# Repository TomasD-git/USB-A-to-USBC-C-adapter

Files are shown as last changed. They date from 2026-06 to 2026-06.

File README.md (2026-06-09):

# USB-A-to-USBC-C-adapter
**Compact USB-A to USB-C adapter, supports USB 3.1 speeds, with stable power**

<details>
<summary>Features</summary>
  
-Small  
-Very fast  
-1 Layer PCBA  
  
</details>

<details>
  <summary>BOM</summary>

# BOM
 
| Name | Purpose | Quantity | Total Cost (USD) | Link | Distributor |
|---|---|---|---|---|---|
| PCB | all components are on this | 1 | 15 | [jlcpcb](https://jlcpcb.com) | jlcpcb |
| ALL components | all components that are on pcb | 1 | 25 | [lcsc](https://lcsc.com) | lcsc |
| | | **Total cost** | **40** | | |

</details>







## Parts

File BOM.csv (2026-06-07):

Name | Purpose | Quantity | Total Cost (USD) | Link | Distributor
PCB | all components are on this | 1 | 15 | https://jlcpcb.com | jlcpcb
ALL components | all components that are on pcb | 1 | 25 | https://lcsc.com | lcsc
 |  | Total cost | 40

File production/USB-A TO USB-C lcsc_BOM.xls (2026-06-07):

JLCPCB BOM Tool - BOM Matching
BOM name：bom-JLCPCB Assembly Order.xlsx |  |  | Download Time：2026-06-08 02:33:23 |  |  |  | * Our matching results are updated in real-time, but stock and prices may change. If it's been over 24 hours, please re-match before placing your order.
PCB Assembled Qty：5 |  |  | Est. Total Price：21.4874
Your BOM |  |  |  |  | Matched Parts |  |  |  |  |  |  | Order Information
Top Designator | Bottom Designator | Comment | Footprint | JLCPCB Part # | Matches | Part # | Manufacturer | Footprint | Description | Category | Warning | JLCPCB Part # | Product link | Lib Type | Qty | Source | Total Price ($)
C1,C10,C2,C4,C7 |  | 100nF | 0402 |  | Select by System | CL05B104KO5NNNC | Samsung Electro-Mechanics | 0402 | 100nF 16V X7R ±10% 0402 Multilayer Ceramic Capacitors MLCC - SMD/SMT ROHS | Multilayer Ceramic Capacitors MLCC - SMD/SMT |  | C1525 | https://jlcpcb.com/partdetail/1877-CL05B104KO5NNNC/C1525 | Basic | 35 | 35 JLCPCB | 0.0735
C3,C5,C8 |  | 1uF | 0603 |  | Select by System | CL10A105KB8NNNC | Samsung Electro-Mechanics | 0603 | 1uF 50V X5R ±10% 0603 Multilayer Ceramic Capacitors MLCC - SMD/SMT ROHS | Multilayer Ceramic Capacitors MLCC - SMD/SMT |  | C15849 | https://jlcpcb.com/partdetail/16531-CL10A105KB8NNNC/C15849 | Basic | 25 | 25 JLCPCB | 0.2675
C6,C9 |  | 10uF | 0805 |  | Select by System | GRM21BR61H106KE43L | Murata Electronics | 0805 | 10uF 50V X5R ±10% 0805 Multilayer Ceramic Capacitors MLCC - SMD/SMT ROHS | Multilayer Ceramic Capacitors MLCC - SMD/SMT |  | C440198 | https://jlcpcb.com/partdetail/439567-GRM21BR61H106KE43L/C440198 | Basic | 14 | 14 JLCPCB | 4.3134
R1 |  | 4.7K | 0603 |  | Unconfirmed | 0603WAF4701T5E | UNI-ROYAL(Uniroyal Elec) | 0603 | -55℃~+155℃ 100mW 4.7kΩ 75V Thick Film Resistor ±1% ±100ppm/℃ 0603 Chip Resistor - Surface Mount ROHS | Chip Resistor - Surface Mount | 1.The comment (0603WAF4701T5E) of this part does not match the one (4.7K) provided in your BOM. Please confirm; | C23162 | https://jlcpcb.com/partdetail/23889-0603WAF4701T5E/C23162 | Basic | 20 | 20 JLCPCB | 0.028
R2 |  | 900K | 0603 |  | Select by Customer | 0603WAF4703T5E | UNI-ROYAL(Uniroyal Elec) | 0603 | -55℃~+155℃ 100mW 470kΩ 75V Thick Film Resistor ±1% ±100ppm/℃ 0603 Chip Resistor - Surface Mount ROHS | Chip Resistor - Surface Mount | 1.The comment (0603WAF4703T5E) of this part does not match the one (900K) provided in your BOM. Please confirm; | C23178 | https://jlcpcb.com/partdetail/23905-0603WAF4703T5E/C23178 | Basic | 20 | 20 JLCPCB | 0.034
R3,R4,R5,R6,R7,R8 |  | 200K | 0603 |  | Unconfirmed | 0603WAF2003T5E | UNI-ROYAL(Uniroyal Elec) | 0603 | -55℃~+155℃ 100mW 200kΩ 75V Thick Film Resistor ±1% ±100ppm/℃ 0603 Chip Resistor - Surface Mount ROHS | Chip Resistor - Surface Mount | 1.The comment (0603WAF2003T5E) of this part does not match the one (200K) provided in your BOM. Please confirm; | C25811 | https://jlcpcb.com/partdetail/26554-0603WAF2003T5E/C25811 | Basic | 40 | 40 JLCPCB | 0.068
R9 |  | 10K | 0603 |  | Unconfirmed | 0603WAF1002T5E | UNI-ROYAL(Uniroyal Elec) | 0603 | -55℃~+155℃ 100mW 10kΩ 75V Thick Film Resistor ±1% ±100ppm/℃ 0603 Chip Resistor - Surface Mount ROHS | Chip Resistor - Surface Mount | 1.The comment (0603WAF1002T5E) of this part does not match the one (10K) provided in your BOM. Please confirm; | C25804 | https://jlcpcb.com/partdetail/26547-0603WAF1002T5E/C25804 | Basic | 20 | 20 JLCPCB | 0.064
U1 |  | TLV75533PDBVR | SOT-23-5_L3.0-W1.7-P0.95-LS2.8-BR |  | Select by System | TLV75533PDBVR | Texas Instruments | SOT-23-5 | -40℃~+125℃@(Tj) 1 238mV@(500mA) 25uA 3.3V 46dB@(100kHz) 5.5V 500mA 71.5uVrms Fixed Over Current Protection、Thermal Shutdown、Input undervoltage protection Positive SOT-23-5 Voltage Regulators - Linear, Low Drop Out (LDO) Regulators ROHS | Voltage Regulators - Linear, Low Drop Out (LDO) Regulators |  | C404027 | https://jlcpcb.com/partdetail/TexasInstruments-TLV75533PDBVR/C404027 | Extended | 5 | 5 JLCPCB | 0.7215
U2 |  | HD3SS3220RNHR | WQFN-30_L4.5-W2.5-P0.4-BL-EP |  | Select by System | HD3SS3220RNHR | Texas Instruments | WQFN-30-EP(2.5x4.5) | -40℃~+85℃ 4.5V~5.5V 5uA I2C Not supported Not supported WQFN-30-EP(2.5x4.5) Battery Management ROHS | Battery Management |  | C165155 | https://jlcpcb.com/partdetail/TexasInstruments-HD3SS3220RNHR/C165155 | Extended | 5 | 5 JLCPCB | 9.4065
USB1 |  | USB-A | USB-A-SMD_U-A-39WD-W-1 |  | Select by System | U-A-39WD-W-1 | Korean Hroparts Elec | SMD | -40℃~+85℃ 1 1,500 Cycles 1.5A 14.25mm 9P Female Surface Mount, Right Angle Type-A USB 3.1 SMD USB Connectors ROHS | USB Connectors |  | C3020886 | https://jlcpcb.com/partdetail/Korean_HropartsElec-U_A_39WD_W1/C3020886 | Extended | 5 | 5 JLCPCB | 1.245
USB2 |  | USB-C | USB-C-SMD_USB-3.1-C-TYPE |  | Select by System | XDBM-0339-1530 | Lian Xin Technology | SMD | -40℃~+85℃ 1 15.5mm 24P 5A Male Surface Mount, Right Angle Type-C USB 3.1 SMD USB Connectors ROHS | USB Connectors |  | C7527710 | https://jlcpcb.com/partdetail/Lian_XinTechnology-XDBM_03391530/C7527710 | Extended | 5 | 5 JLCPCB | 5.266

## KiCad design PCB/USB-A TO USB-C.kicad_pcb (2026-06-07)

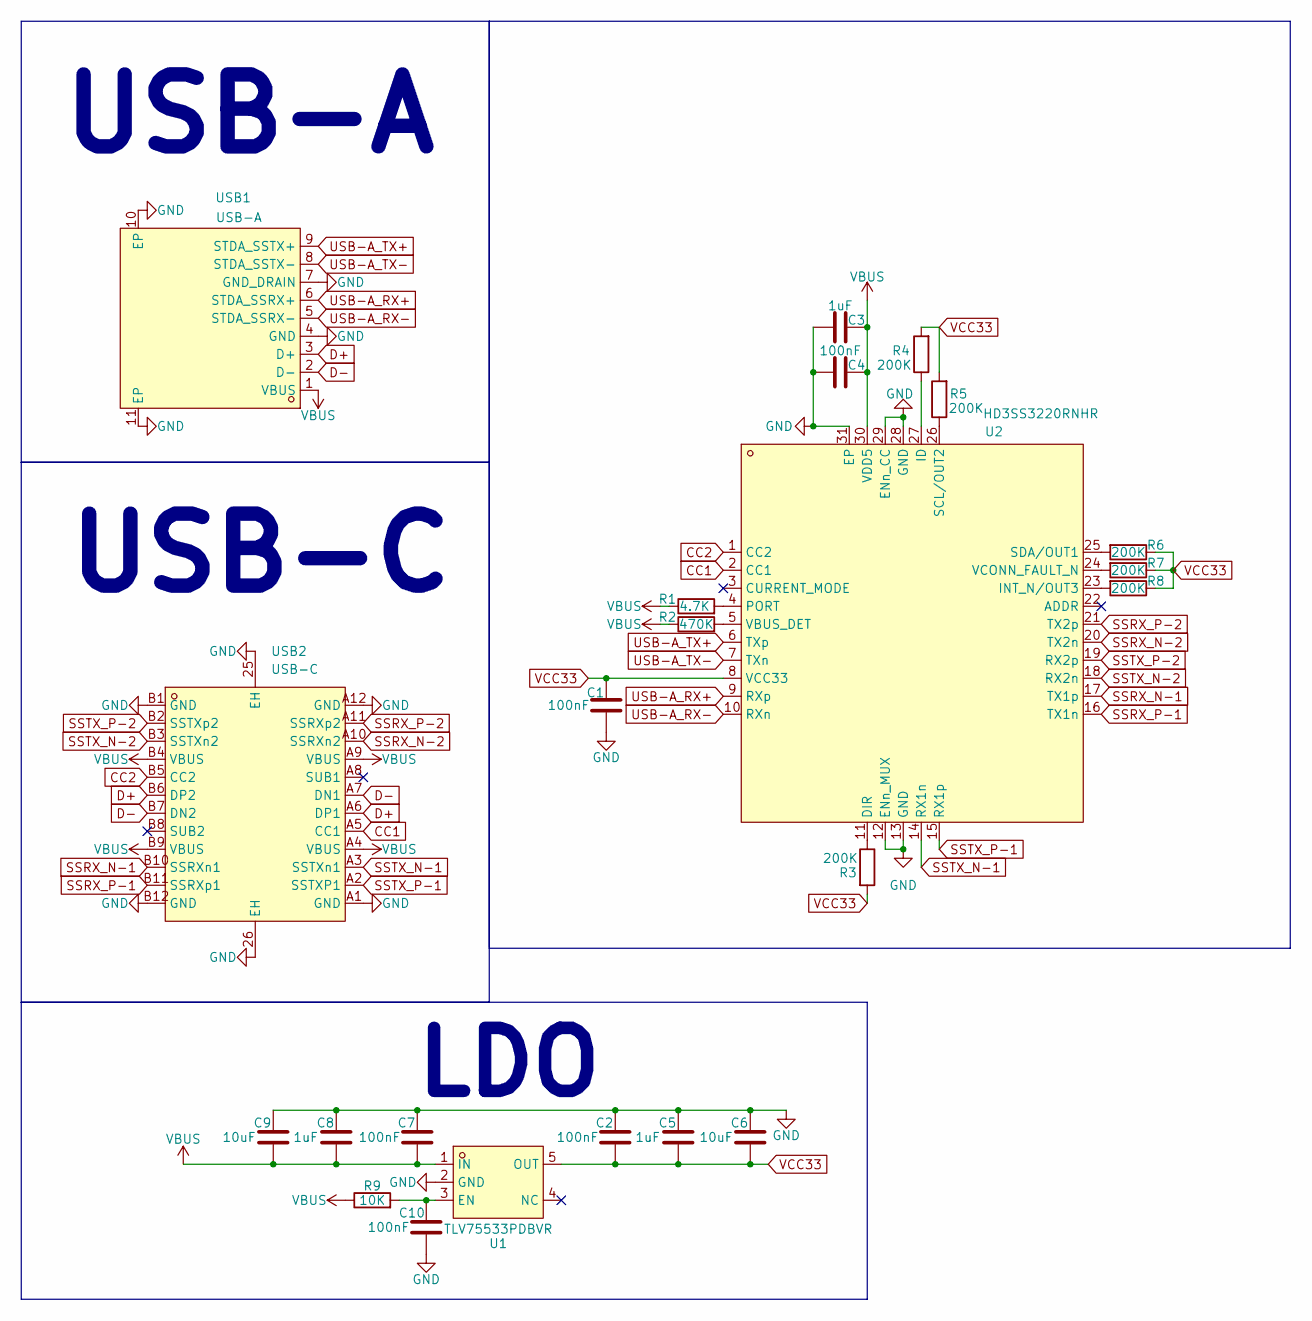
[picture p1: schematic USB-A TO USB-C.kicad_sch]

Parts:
C1, C2, C4, C7, C10: 100nF; C_0402_1005Metric_Pad0.74x0.62mm_HandSolder
C3, C5, C8: 1uF; C_0603_1608Metric
C6, C9: 10uF; C_0805_2012Metric
R1: 4.7K; R_0603_1608Metric
R2: 470K; R_0603_1608Metric
R3, R4, R5, R6, R7, R8: 200K; R_0603_1608Metric
R9: 10K; R_0603_1608Metric
U1: TLV75533PDBVR; SOT-23-5_L3.0-W1.7-P0.95-LS2.8-BR; MPN TLV75533PDBVR; LCSC Part C404027
U2: HD3SS3220RNHR; WQFN-30_L4.5-W2.5-P0.4-BL-EP; MPN HD3SS3220RNHR; LCSC Part C165155
USB1: USB-A; USB-A-SMD_U-A-39WD-W-1; MPN U-A-39WD-W-1; LCSC Part C3020886
USB2: USB-C; USB-C-SMD_USB-3.1-C-TYPE; MPN XDBM-0339-1530; LCSC Part C7527710

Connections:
CC1: U2.2 (CC1), USB2.A5 (CC1)
CC2: U2.1 (CC2), USB2.B5 (CC2)
D+: USB1.3 (D+), USB2.A6 (DP1), USB2.B6 (DP2)
D-: USB1.2 (D-), USB2.A7 (DN1), USB2.B7 (DN2)
GND: C1.1, C2.2, C3.1, C4.1, C5.2, C6.2, C7.2, C8.2, C9.2, C10.1, U1.2 (GND), U2.12 (ENn_MUX), U2.13 (GND), U2.28 (GND), U2.29 (ENn_CC), U2.31 (EP), USB1.4 (GND), USB1.7 (GND_DRAIN), USB1.10 (EP), USB1.11 (EP), USB2.25 (EH), USB2.26 (EH), USB2.A1 (GND), USB2.A12 (GND), USB2.B1 (GND), USB2.B12 (GND)
unnamed: C10.2, R9.2, U1.3 (EN)
unnamed: R3.1, U2.11 (DIR)
unnamed: R4.1, U2.27 (ID)
unnamed: R8.2, U2.23 (INT_N/OUT3)
unnamed: R1.2, U2.4 (PORT)
unnamed: R5.1, U2.26 (SCL/OUT2)
unnamed: R6.2, U2.25 (SDA/OUT1)
unnamed: R2.2, U2.5 (VBUS_DET)
unnamed: R7.2, U2.24 (VCONN_FAULT_N)
SSRX_N-1: U2.17 (TX1p), USB2.B10 (SSRXn1)
SSRX_N-2: U2.20 (TX2n), USB2.A10 (SSRXn2)
SSRX_P-1: U2.16 (TX1n), USB2.B11 (SSRXp1)
SSRX_P-2: U2.21 (TX2p), USB2.A11 (SSRXp2)
SSTX_N-1: U2.14 (RX1n), USB2.A3 (SSTXn1)
SSTX_N-2: U2.18 (RX2n), USB2.B3 (SSTXn2)
SSTX_P-1: U2.15 (RX1p), USB2.A2 (SSTXP1)
SSTX_P-2: U2.19 (RX2p), USB2.B2 (SSTXp2)
USB-A_RX+: U2.9 (RXp), USB1.6 (STDA_SSRX+)
USB-A_RX-: U2.10 (RXn), USB1.5 (STDA_SSRX-)
USB-A_TX+: U2.6 (TXp), USB1.9 (STDA_SSTX+)
USB-A_TX-: U2.7 (TXn), USB1.8 (STDA_SSTX-)
VBUS: C3.2, C4.2, C7.1, C8.1, C9.1, R1.1, R2.1, R9.1, U1.1 (IN), U2.30 (VDD5), USB1.1 (VBUS), USB2.A4 (VBUS), USB2.A9 (VBUS), USB2.B4 (VBUS), USB2.B9 (VBUS)
VCC33: C1.2, C2.1, C5.1, C6.1, R3.2, R4.2, R5.2, R6.1, R7.1, R8.1, U1.5 (OUT), U2.8 (VCC33)

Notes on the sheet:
USB-C
USB-A
LDO

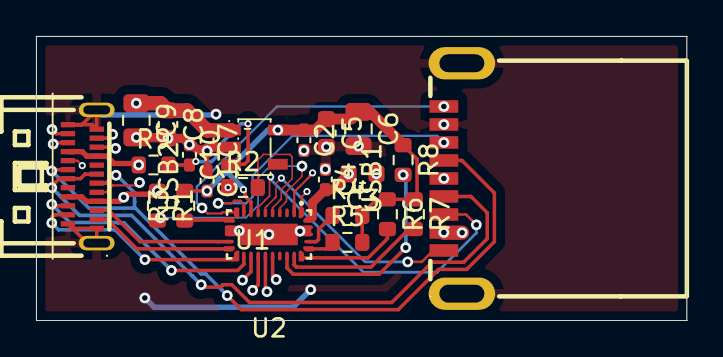
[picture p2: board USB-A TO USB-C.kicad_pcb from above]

Board: 4 copper layers, 36.1 x 15.8 mm, 23 parts (0 on the bottom side), 28 nets.

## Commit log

2026-06-07 Add BOM section to README
    Added a Bill of Materials (BOM) section detailing components and costs.
2026-06-09 added new pcb files
    [USB-A TO USB-C.kicad_pcb, USB-A TO USB-C.kicad_sch]
2026-06-09 Update README with features and BOM sections
    Added features section to README with details.
